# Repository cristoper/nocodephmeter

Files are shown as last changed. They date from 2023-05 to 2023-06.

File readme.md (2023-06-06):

This is a pH meter with temperature compensation and digital readout (but no microcontroller) created as part of [Hackaday's 2023 Op-Amp Challenge](https://hackaday.io/contest/190312-op-amp-challenge). It is still under active development. For more information see it's project page:

https://hackaday.io/project/191424-no-code-ph-meter

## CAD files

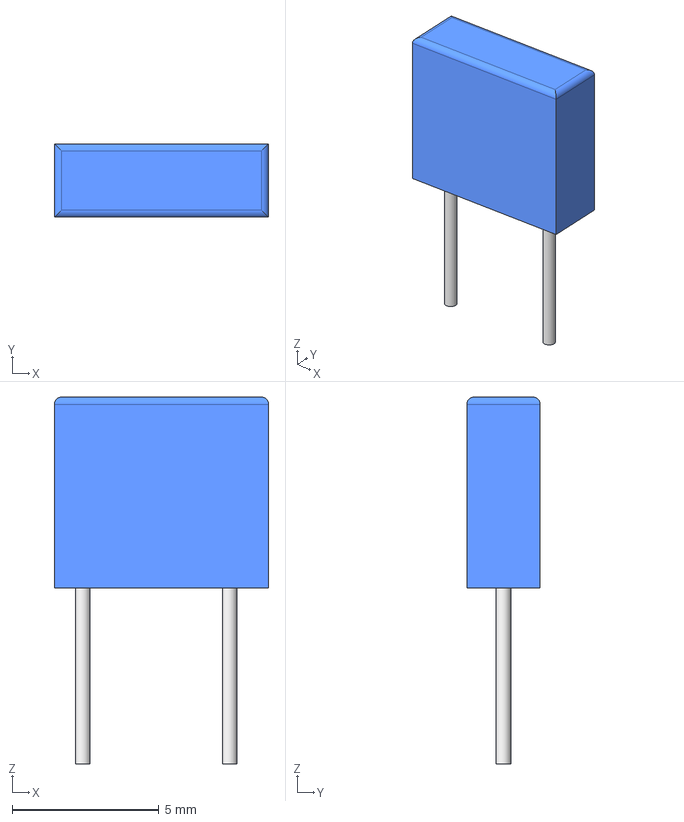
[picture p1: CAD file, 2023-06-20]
film_cap.step
7.30 x 2.50 x 12.5 mm

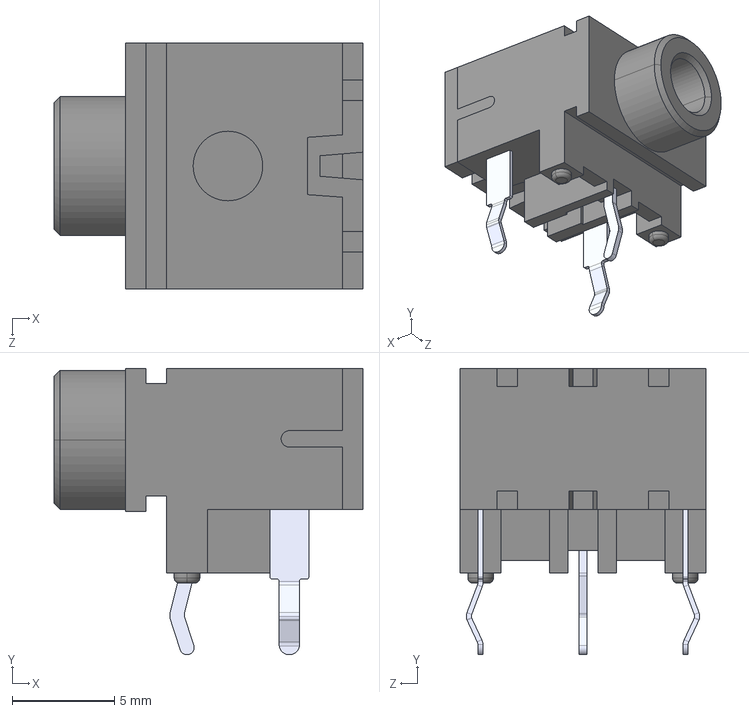
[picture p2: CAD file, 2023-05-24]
STX-3120-3B/STX-3120-3B.step
15.1 x 14.0 x 12.0 mm

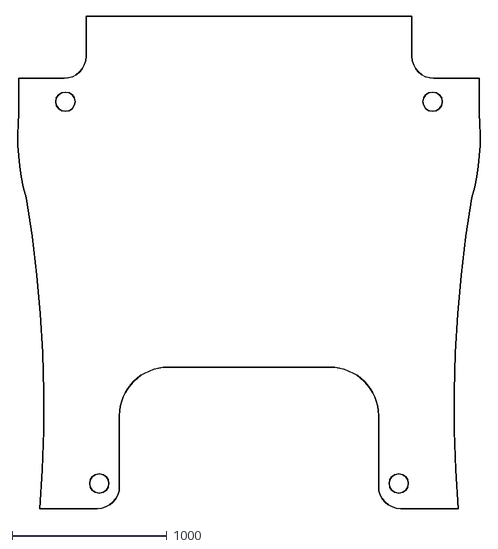
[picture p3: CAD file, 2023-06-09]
wm-35-top-pot-cutouts.dxf
3013.5 x 3184.0

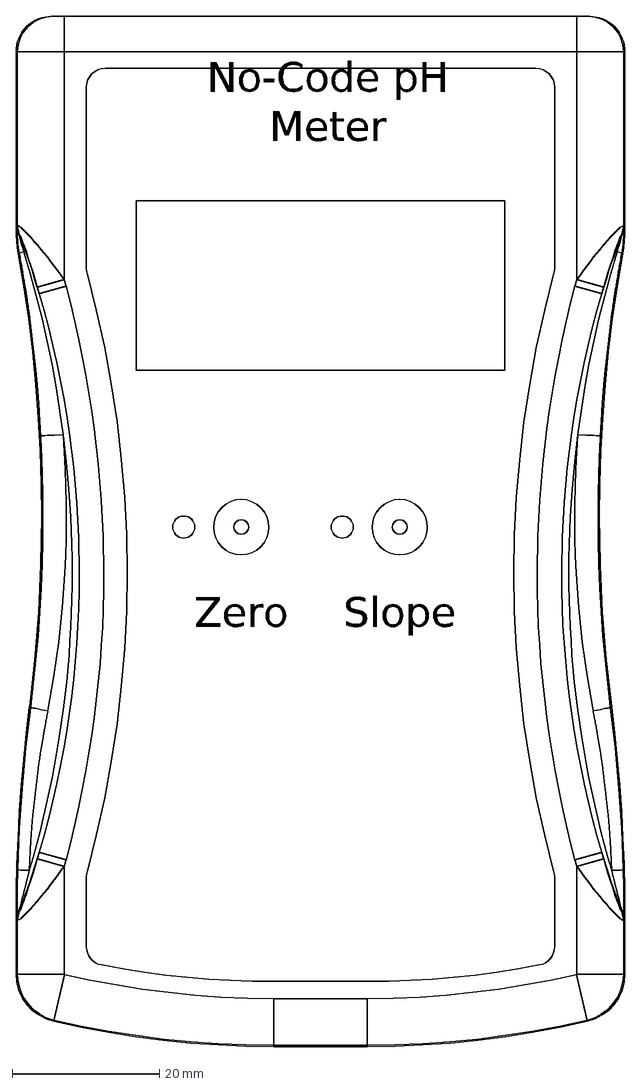
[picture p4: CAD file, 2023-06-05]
label-templates.dxf
No-Code pH Meter
Zero
Slope

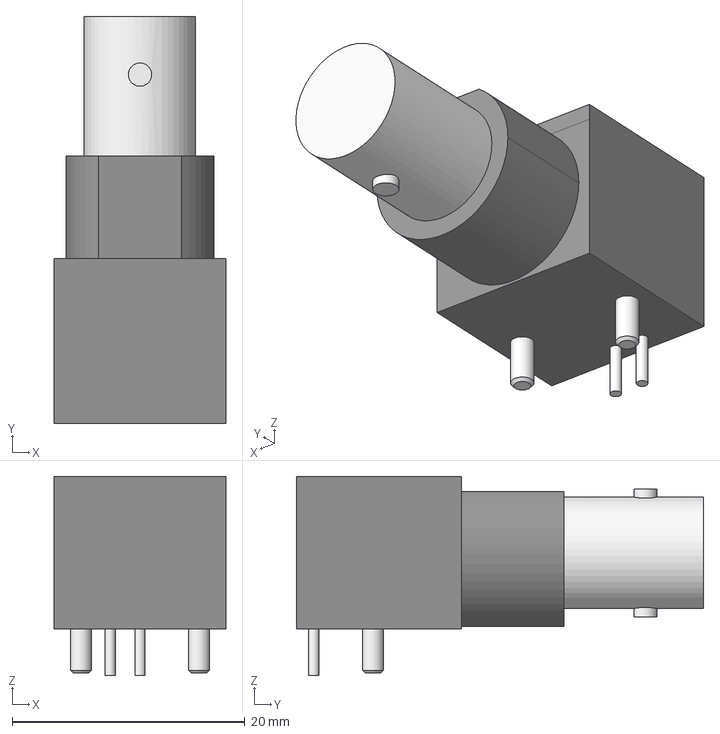
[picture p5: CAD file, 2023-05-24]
bnc_model.step
14.8 x 35.0 x 17.1 mm

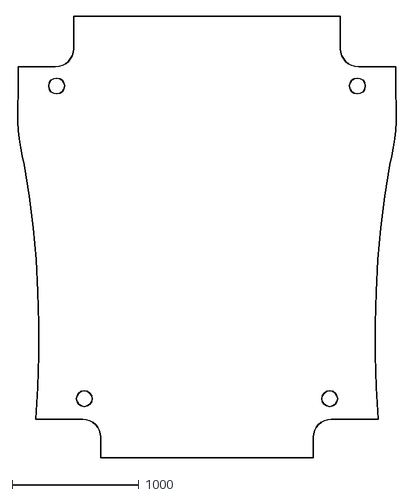
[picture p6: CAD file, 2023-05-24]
wm-35-top.dxf
3013.5 x 3489.0

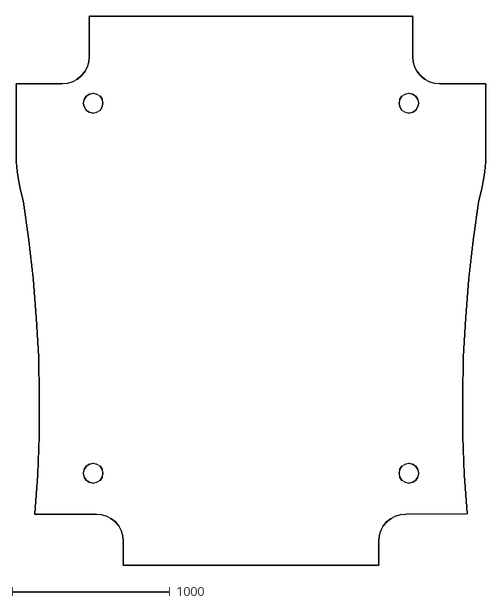
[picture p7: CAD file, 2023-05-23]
wm-35-bottom.dxf
2975.0 x 3477.0

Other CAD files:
bnc_model.FCStd
film_cap.FCStd

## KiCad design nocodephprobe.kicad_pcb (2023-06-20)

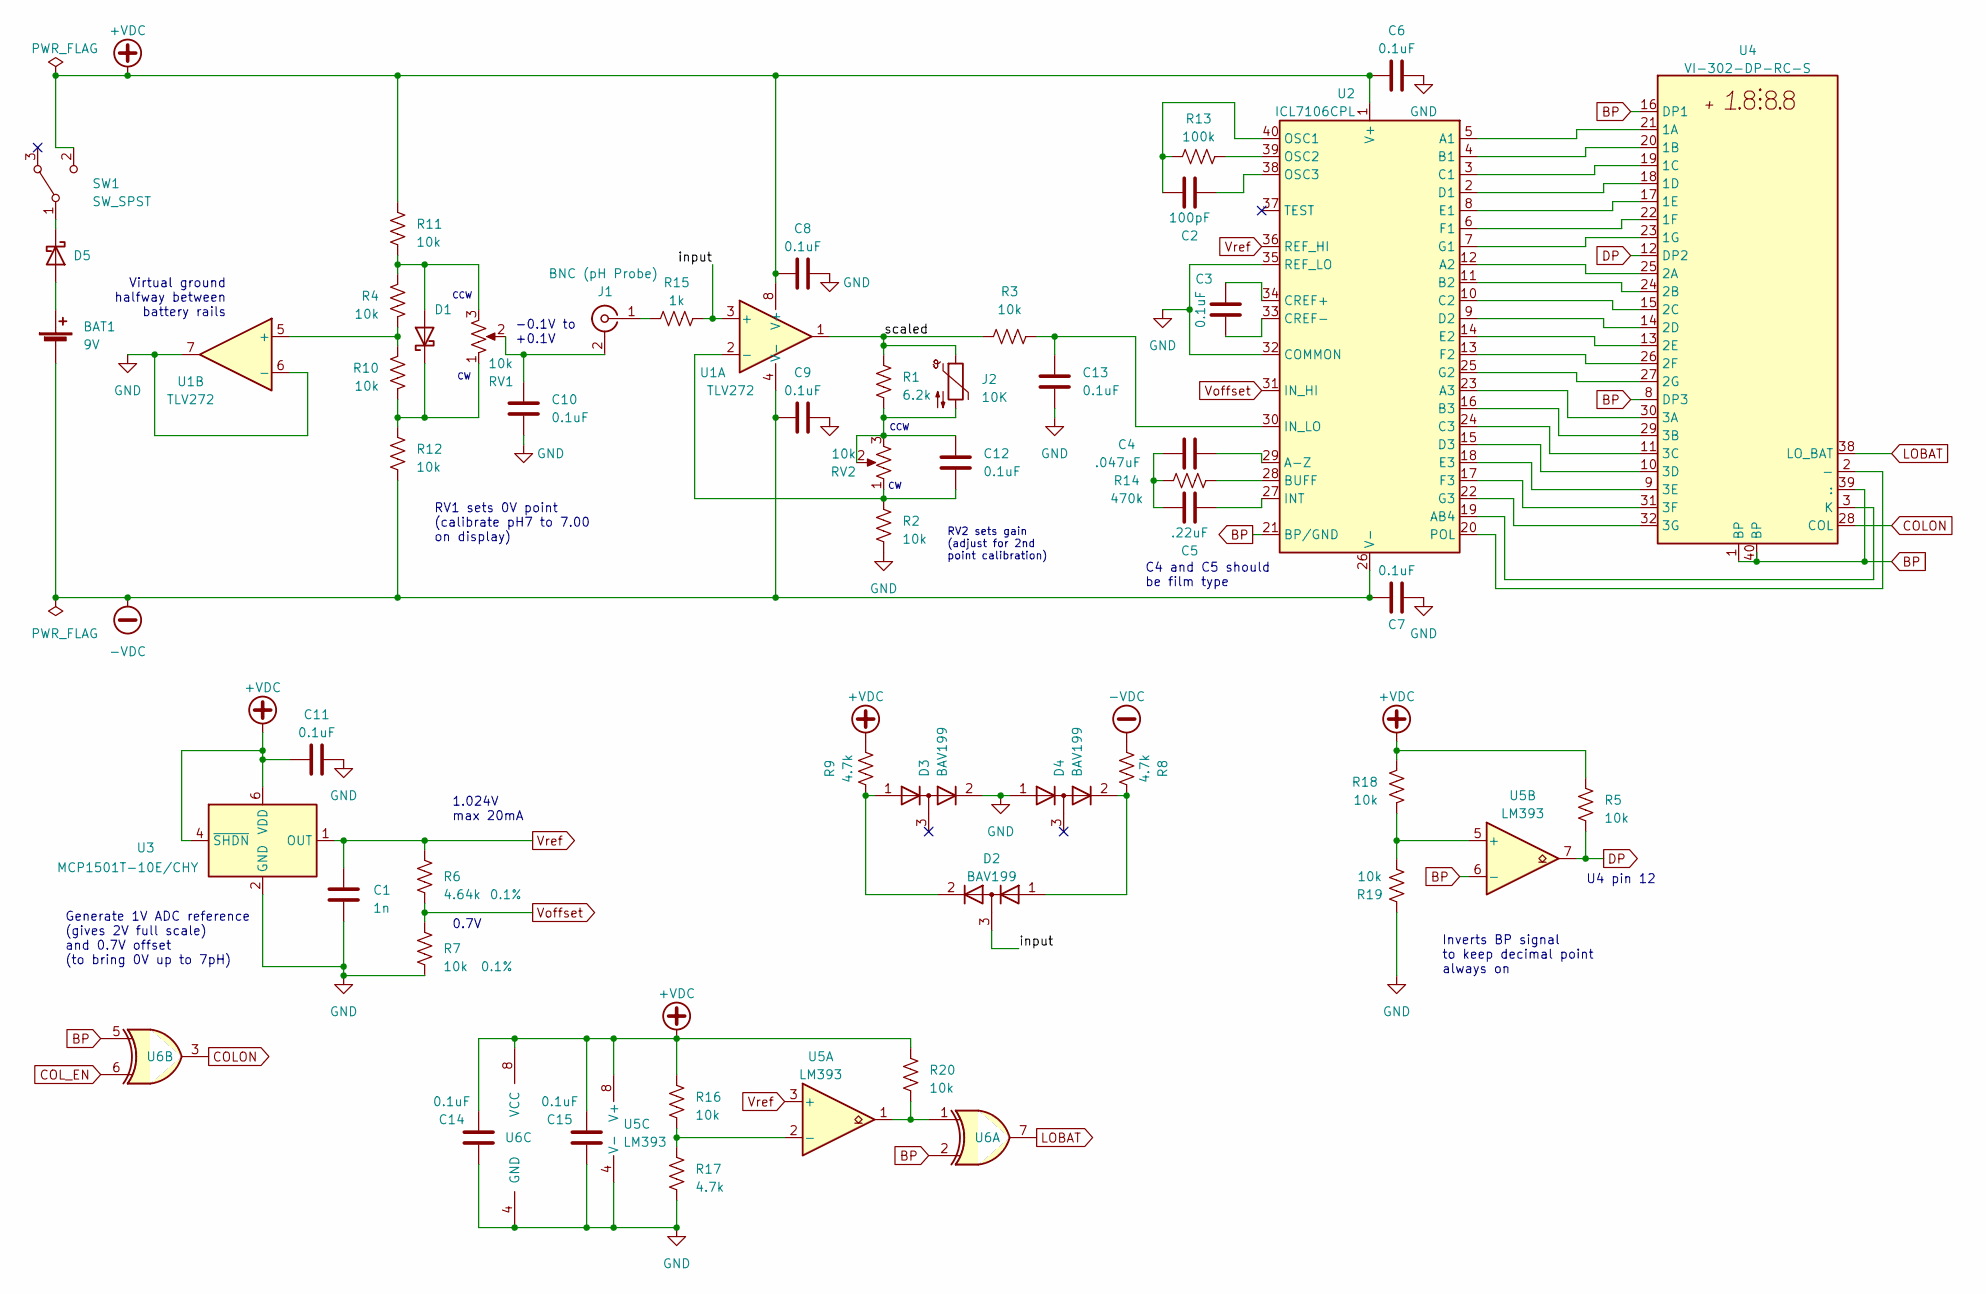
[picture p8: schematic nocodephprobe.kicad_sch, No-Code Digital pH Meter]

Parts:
BAT1: 9V; JST_XH_B2B-XH-A_1x02_P2.50mm_Vertical
C1: 1n; C_0805_2012Metric_Pad1.18x1.45mm_HandSolder
C2: 100pF; C_0805_2012Metric_Pad1.18x1.45mm_HandSolder
C3, C6, C7, C8, C9, C10, C11, C12, C13, C14, C15: 0.1uF; C_0805_2012Metric_Pad1.18x1.45mm_HandSolder
C4: .047uF; C_0805_2012Metric_Pad1.18x1.45mm_HandSolder
C5: .22uF; C_Rect_L18.0mm_W6.0mm_P15.00mm_FKS3_FKP3
D1, D5: BAT54-Q; TSOT-23_HandSoldering
D2, D3, D4: BAV199; SOT-23
J1: BNC (pH Probe); BNC_Amphenol_031-6575_Horizontal; digikey 2057-RF1-01K-D-00-50-BK-HDW-ND
J2: 10K; KYCON_STX-3120-3B
R1: 6.2k; R_0805_2012Metric_Pad1.20x1.40mm_HandSolder
R2, R3, R4, R5, R10, R11, R12, R16, R18, R19, R20: 10k; R_0805_2012Metric_Pad1.20x1.40mm_HandSolder
R6: 4.64k; R_0805_2012Metric_Pad1.20x1.40mm_HandSolder; Tolerance 0.1%
R7: 10k; R_0805_2012Metric_Pad1.20x1.40mm_HandSolder; Tolerance 0.1%
R8, R9, R17: 4.7k; R_0805_2012Metric_Pad1.20x1.40mm_HandSolder
R13: 100k; R_0805_2012Metric_Pad1.20x1.40mm_HandSolder
R14: 470k; R_0805_2012Metric_Pad1.20x1.40mm_HandSolder
R15: 1k; R_0805_2012Metric_Pad1.20x1.40mm_HandSolder
RV1, RV2: 10k; JST_XH_B3B-XH-A_1x03_P2.50mm_Vertical
SW1: SW_SPST; JST_XH_B2B-XH-A_1x02_P2.50mm_Vertical
U1: TLV272; SOIC-8_3.9x4.9mm_P1.27mm
U2: ICL7106CPL; DIP-40_W15.24mm
U3: MCP1501T-10E/CHY; SOT-23-6
U4: VI-302-DP-RC-S; DE113-XX-XX
U5: LM393; TSSOP-8_4.4x3mm_P0.65mm
U6: 74HC2G86; TSSOP-8_3x3mm_P0.65mm

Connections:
+VDC: C6.1, C8.1, C11.1, C14.1, C15.1, R5.2, R9.1, R11.2, R16.2, R18.1, R20.2, SW1.2 (C), U1.8 (V+), U2.1 (V+), U3.4 (~SHDN), U3.6 (VDD), U5.8 (V+), U6.8 (VCC)
-VDC: BAT1.2 (-), C7.1, C9.1, R8.2, R12.1, U1.4 (V-), U2.26 (V-)
/input: D2.3 (common), R15.1, U1.3 (+)
/scaled: J2.1, R1.2, R3.1, U1.1
BP: U2.21 (BP/GND), U4.1 (BP), U4.8 (DP3), U4.16 (DP1), U4.39 (:), U4.40 (BP), U5.6 (-), U6.2, U6.5
COLON: U4.28 (COL), U6.3
COL_EN: U6.6
DP: R5.1, U4.12 (DP2), U5.7
GND: C1.2, C6.2, C7.2, C8.2, C9.2, C10.1, C11.2, C13.1, C14.2, C15.2, D3.2 (K), D4.1 (A), R2.1, R7.1, R17.1, R19.2, U1.6 (-), U1.7, U2.32 (COMMON), U2.35 (REF_LO), U3.2 (GND), U3.3 (GND), U3.5 (GND), U5.4 (V-), U6.4 (GND)
LOBAT: U4.38 (LO_BAT), U6.7
unnamed: BAT1.1 (+), D5.1 (A)
unnamed: C4.2, C5.2, R14.2
unnamed: C12.2, J2.5, R1.1, RV2.2, RV2.3
unnamed: D1.1 (A), R4.2, R11.1, RV1.3
unnamed: D1.3 (K), R10.1, R12.2, RV1.1
unnamed: D2.1 (A), D4.2 (K), R8.1
unnamed: D2.2 (K), D3.1 (A), R9.2
unnamed: D5.3 (K), SW1.1 (B)
unnamed: C10.2, J1.2 (Ext), RV1.2
unnamed: J1.1 (In), R15.2
unnamed: R20.1, U5.1, U6.1
unnamed: C12.1, R2.2, RV2.1, U1.2 (-)
unnamed: R4.1, R10.2, U1.5 (+)
unnamed: U2.5 (A1), U4.21 (1A)
unnamed: U2.12 (A2), U4.25 (2A)
unnamed: U2.23 (A3), U4.30 (3A)
unnamed: C4.1, U2.29 (A-Z)
unnamed: U2.19 (AB4), U4.3 (K)
unnamed: U2.4 (B1), U4.20 (1B)
unnamed: U2.11 (B2), U4.24 (2B)
unnamed: U2.16 (B3), U4.29 (3B)
unnamed: R14.1, U2.28 (BUFF)
unnamed: U2.3 (C1), U4.19 (1C)
unnamed: U2.10 (C2), U4.15 (2C)
unnamed: U2.24 (C3), U4.11 (3C)
unnamed: C3.1, U2.34 (CREF+)
unnamed: C3.2, U2.33 (CREF-)
unnamed: U2.2 (D1), U4.18 (1D)
unnamed: U2.9 (D2), U4.14 (2D)
unnamed: U2.15 (D3), U4.10 (3D)
unnamed: U2.8 (E1), U4.17 (1E)
unnamed: U2.14 (E2), U4.13 (2E)
unnamed: U2.18 (E3), U4.9 (3E)
unnamed: U2.6 (F1), U4.22 (1F)
unnamed: U2.13 (F2), U4.26 (2F)
unnamed: U2.17 (F3), U4.31 (3F)
unnamed: U2.7 (G1), U4.23 (1G)
unnamed: U2.25 (G2), U4.27 (2G)
unnamed: U2.22 (G3), U4.32 (3G)
unnamed: C5.1, U2.27 (INT)
unnamed: C13.2, R3.2, U2.30 (IN_LO)
unnamed: C2.2, R13.1, U2.40 (OSC1)
unnamed: R13.2, U2.39 (OSC2)
unnamed: C2.1, U2.38 (OSC3)
unnamed: U2.20 (POL), U4.2 (-)
unnamed: R16.1, R17.2, U5.2 (-)
unnamed: R18.2, R19.1, U5.5 (+)
Voffset: R6.1, R7.2, U2.31 (IN_HI)
Vref: C1.1, R6.2, U2.36 (REF_HI), U3.1 (OUT), U5.3 (+)

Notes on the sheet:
U4 pin 12
C4 and C5 should be film type
1.024V max 20mA
RV2 sets gain (adjust for 2nd point calibration)
Virtual ground halfway between battery rails
RV1 sets 0V point (calibrate pH7 to 7.00 on display)
Generate 1V ADC reference (gives 2V full scale) and 0.7V offset (to bring 0V up to 7pH)
-0.1V to +0.1V
0.7V
CCW
Inverts BP signal to keep decimal point always on

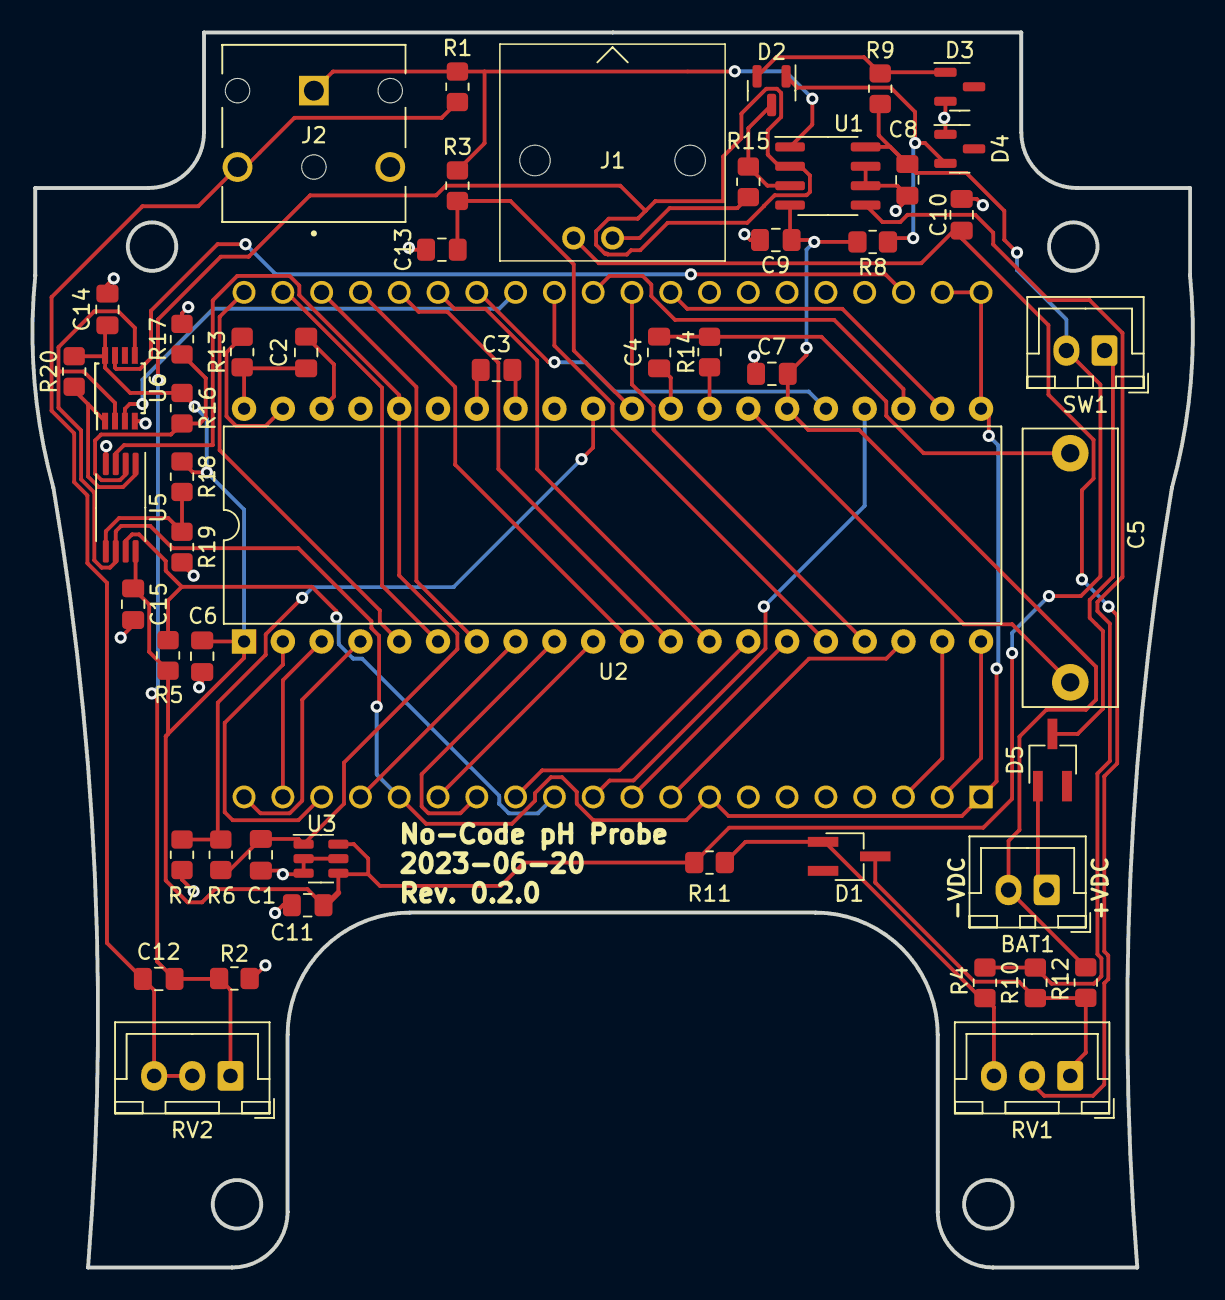
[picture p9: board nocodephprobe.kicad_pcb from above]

Board: 2 copper layers, 76.0 x 80.9 mm, 52 parts (1 on the bottom side), 58 nets.

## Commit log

2023-05-20 Initial commit: finished basic schematic capture
    Now to choose enclosure and lay out PCB.
    [nocodephprobe.kicad_pcb, nocodephprobe.kicad_sch, ntcvalue.ods]
2023-05-23 Use 10k pots instead of 100k
    [nocodephprobe.kicad_sch]
2023-05-23 Track board edge drawings
    [wm-35-bottom.dxf, wm-35-top.dxf]
2023-05-23 Use only 1 diode in offset circuit
    [nocodephprobe.kicad_sch]
2023-05-24 Add header footprints to bat and pots
    [nocodephprobe.kicad_sch]
2023-05-24 Add some 3d models
    Including a model for the bnc connector drawn in FreeCAD.
    [STX-3120-3B.step, bnc_model.FCStd, nocodephprobe.kicad_pcb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]
2023-05-24 Fix PCB bosses on board outline!
    [nocodephprobe.kicad_pcb, wm-35-top.dxf]
2023-05-24 Track bnc model
    [bnc_model.step]
2023-05-25 Add cutout for pots to pcb outline
    [nocodephprobe.kicad_pcb, wm-35-top-pot-cutouts.dxf]
2023-05-25 track c5 3d model
    [wurth_pp_18_6_p15.FCStd, wurth_pp_18_6_p15.step]
2023-05-25 Initial routing of nets
    No DRC errors, but some mess vias and traces.
    [nocodephprobe.kicad_pcb, nocodephprobe.kicad_sch]
2023-05-26 Remove redundant voltage divider
    This removes two resistors.
    [nocodephprobe.kicad_pcb, nocodephprobe.kicad_sch]
2023-05-26 Add revision and github text to silkscreen
    [nocodephprobe.kicad_pcb]
2023-05-26 Rework a few traces
    [nocodephprobe.kicad_pcb]
2023-05-26 Add guard ring around probe input
    [nocodephprobe.kicad_pcb]
2023-05-26 Correct Cref (C3 value)
    [nocodephprobe.kicad_pcb, nocodephprobe.kicad_sch]
2023-05-27 Update some gerber settings for jlcpcb
    [nocodephprobe.kicad_pcb]
2023-05-27 Add silkscreen labels to power nets
    [nocodephprobe.kicad_pcb]
2023-05-28 pcb: move trace away from edge
    [nocodephprobe.kicad_pcb]
2023-05-28 pcb: make d1 and r12 more compact
    [nocodephprobe.kicad_pcb]
2023-05-28 pcb: move components away from edge and eliminate 2 vias
    [nocodephprobe.kicad_pcb]
2023-05-28 pcb: eliminate 2 vias
    [nocodephprobe.kicad_pcb]
2023-05-30 schematic: add decoupling caps to op-amp
    [nocodephprobe.kicad_sch]
2023-05-30 Fix op-amp power supply
    Add an 7805 linear regulator to keep voltage within max supply, and add
    decoupling caps.
    [nocodephprobe.kicad_pcb, nocodephprobe.kicad_sch]
2023-06-02 Remove fmask all the way around guard trace
    Based on prototype pcbs from jlcpcb, I don't think solder bridges will
    be an issue.
    [nocodephprobe.kicad_pcb]
2023-06-03 pcb: fix lcd footprint
    The pins are actually 1.27mm offset (so a 2.54mm wider footprint):
    https://media.digikey.com/pdf/Data%20Sheets/Varitronix%20PDFs/Displays.pdf
    [nocodephprobe.kicad_pcb, nocodephprobe.kicad_sch]
2023-06-04 Transpose R6 and R7
    In the prototype the voffset was 0.3V instead of 0.7V!
    [nocodephprobe.kicad_pcb, nocodephprobe.kicad_sch]
2023-06-04 pcb: fix LCD pinout!
    Plus it was much easier to route with the correct pin numbering (many
    fewer vias)
    [nocodephprobe.kicad_pcb]
2023-06-05 schematic: add pn and datasheet to ntc
    [nocodephprobe.kicad_sch]
2023-06-05 Add decoupling caps to potentiometers
    This also changes the 7805 to a smaller footprint
    [nocodephprobe.kicad_pcb, nocodephprobe.kicad_sch]
2023-06-05 Change D1 to a Schottky diode
    This will reduce the range of the zero calibration from +/- 0.3V to +/-
    0.15V and make the setting less finicky.
    [nocodephprobe.kicad_pcb, nocodephprobe.kicad_sch]
2023-06-05 Flip pots so that CW increases pH during calibration
    [nocodephprobe.kicad_pcb, nocodephprobe.kicad_sch]
2023-06-05 Track label template
    [label-templates.dxf]
2023-06-05 pcb: update silkscreen for new github url
    [nocodephprobe.kicad_pcb]
2023-06-06 Add header for power switch
    [nocodephprobe.kicad_pcb, nocodephprobe.kicad_sch]
2023-06-06 Regulate entire circuit to 5V
    Though in the future I'd like to run the 7106 directly from the battery,
    that requires centering the 7805 and lmv358a at the virtual ground.
    [nocodephprobe.kicad_sch]
2023-06-06 pcb: update PCB to reflect schematic (power 7106 from 5V)
    I am really unhappy with the power routing and need to rework the whole
    power system so the 7106 can be powered directly from the battery
    anyway.
    [nocodephprobe.kicad_pcb]
2023-06-06 schematic: tidy power switch
    [nocodephprobe.kicad_sch]
2023-06-09 schematic: simplify power and decoupling
    The big change is switch from the lmv358a to the tlv272:
    - TLV272 can operate from up to 16.5V supply, which means we can run it
    directly from the 9V battery (no 7805 or zeners required)
    - It has better typical Vos (500uV), Input Offset Current (1pA), and
    Input Bias Current (1PA)
    - It has worse max offset specs (Vos=5mV, Iio/Iib = 60pA), but they
    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
    [nocodephprobe.kicad_sch]
2023-06-09 pcb: make cutouts for pots larger
    This makes it less critical to drill holes in panel at exact location
    [wm-35-top-pot-cutouts.dxf]
2023-06-11 pcb: route improved power and headers
    [nocodephprobe.kicad_pcb, nocodephprobe.kicad_sch]
2023-06-11 pcb: move switch header to above C5
    [nocodephprobe.kicad_pcb]
2023-06-11 pcb: use 2-pin header for RV2
    [nocodephprobe.kicad_pcb, nocodephprobe.kicad_sch]
2023-06-14 Implement [optional] input protection
    D2 will clamp the input to 3 diode drops from either rail (~1.8V). This
    keeps the input within the safe range for the TLV272. R15 limits the
    current in case of overvoltage. The diodes in D3 and D4 set a bias point
    two diode drops below the positive rail and above the negative rail to
    minimize the reverse voltage (and therefore leakage current) across the
    D2 diodes.
    Since the D2 diodes are reverse-biased normally, they should not affect
    normal input. However, the tricky part is finding diodes with low enough
    (preferabley <10pA) reverse leakage current. These BAV199 diodes are by
    far the most cost effective solution I found ($0.18 in single quantities
    of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
    [nocodephprobe.kicad_pcb, nocodephprobe.kicad_sch]
2023-06-14 Specify cheaper Schottky diodes
    Also add one as reverse-voltage protection to protect op-amp input (D5)
    [nocodephprobe.kicad_pcb, nocodephprobe.kicad_sch]
2023-06-14 Use SPDT for power switch
    I decided on these MTS-103 mini toggle switches, to be mounted next to BNC
    (and connected with wires to JST XH connector):
    https://www.amazon.com/dp/B07CJFVZ7M
    [nocodephprobe.kicad_pcb, nocodephprobe.kicad_sch]
2023-06-15 Revert to using 3-pin connector for RV2
    I think it is more flexible. Can always use a 3-pin plug with only 2
    wires populated.
    [nocodephprobe.kicad_pcb, nocodephprobe.kicad_sch]
2023-06-20 Low battery indicator
    This change adds a comparator and xor gate to implement a low-battery
    indicator. When the positive rail goes below about 3V, then the output
    of U5A goes high. The output of U5A is XOR'd with the backplane which
    inverts the backplane when it is high, turning on the LOBAT LCD
    indicator.
    I'm using the spare coparator to replace the 2n7002 to keep the decimal
    point on.
    I got this all layed out on the PCB, but I'm increasingly unhappy with
    how stringy the VDC+ trace is becoming. I think I will try laying it out
    as a 4-layer board.
    [nocodephprobe.kicad_pcb, nocodephprobe.kicad_sch]
2023-06-20 cheaper, smaller film caps
    After reading this app note (The Integrating A/D Converter (ICL7135))
    I'm convinced a big poolypropylene capacitor is not necessary. But I do
    think using a film type for the autozero is a good idea.
    "is of no consequence in this circuit. The dielectric absorption of
    the reference and auto-zero capacitors are only important at
    power-on or when the circuit is recovering from an overload.
    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
    [nocodephprobe.kicad_sch]
2023-06-20 pcb: new 3D model for smaller caps
    [film_cap.FCStd, film_cap.step, wurth_pp_18_6_p15.FCStd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]
2023-06-21 Use larger, film cap for Cref
    [nocodephprobe.kicad_sch]
2023-06-21 Reduce decoupling to gnd
    This is an attempt to reduce the capacitive load on the output of U1B
    (the virtual gnd) to keep it more stable. The isolation resistor R21
    should also help even if it introduces low-frequency gnd errors.
    [nocodephprobe.kicad_sch]
